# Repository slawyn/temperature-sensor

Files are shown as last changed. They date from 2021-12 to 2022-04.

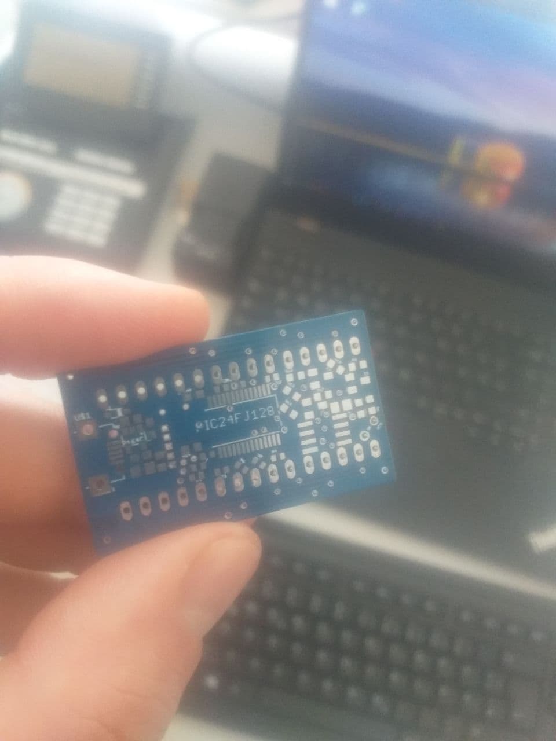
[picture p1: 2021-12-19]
pictures/photo_2021-05-17_21-20-24.jpg

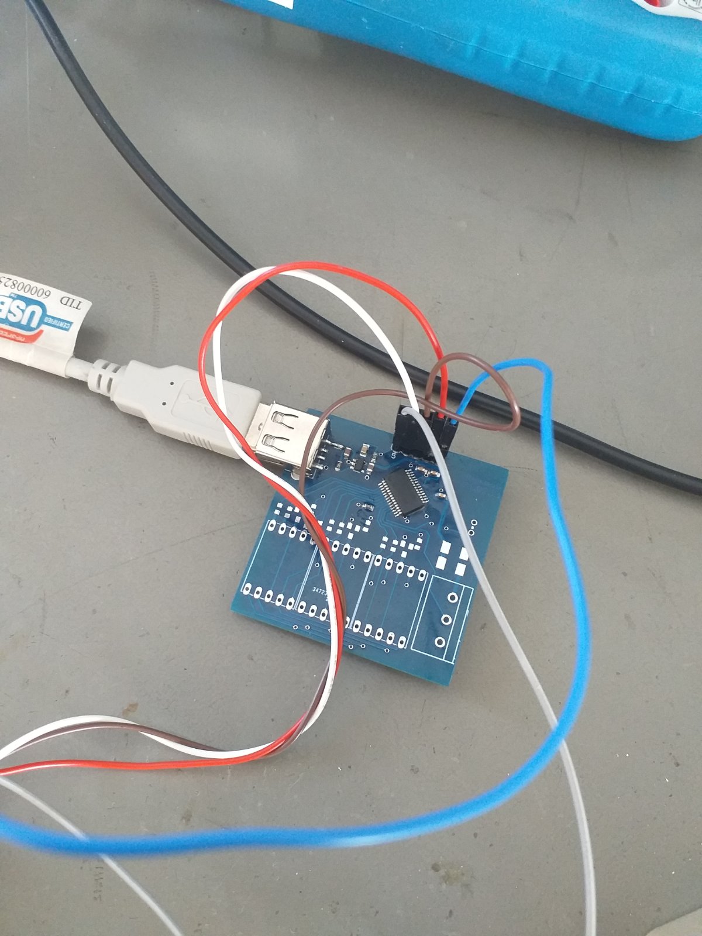
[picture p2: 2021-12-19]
pictures/viber_image_2021-04-01_18-56-37.jpg

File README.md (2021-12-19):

This project focuses on creating a simple usb-powered hardware that measures temperature.
*v1 - initial faulty design. CA CK have for 7-segment been switched
*v2 - improved doubled-sided design. Potentiometer replaced by an digital spi controller poti. Problem with the vias.
*v3 - wip

Use "Gerberlogix" to viewer gerber files.

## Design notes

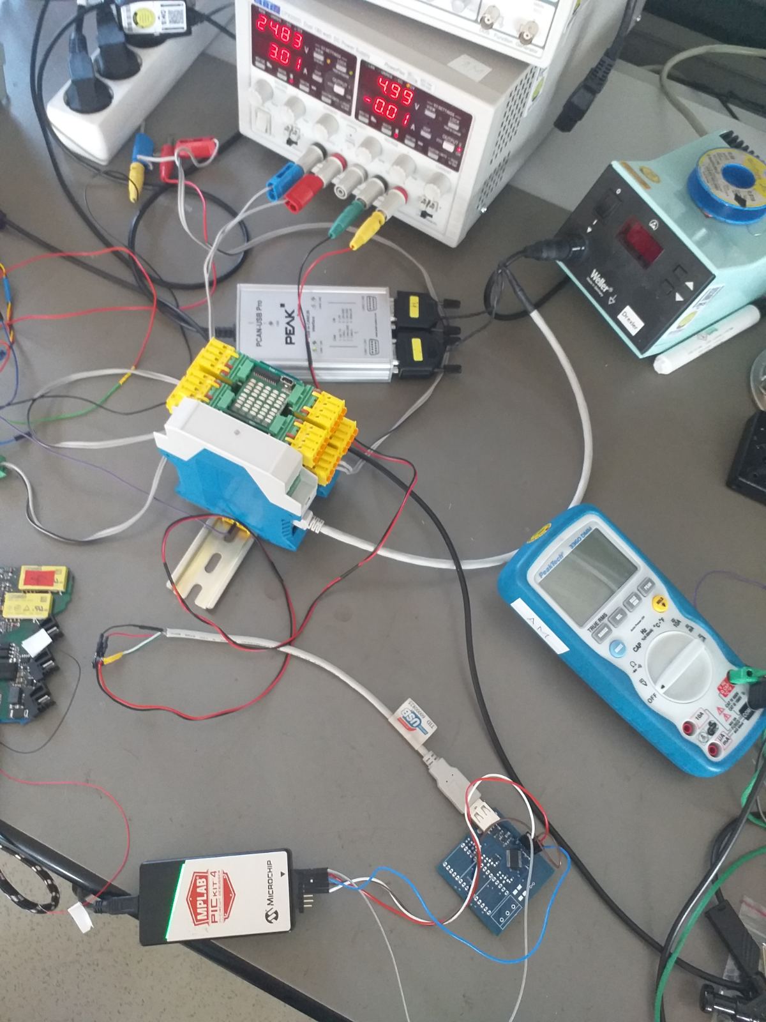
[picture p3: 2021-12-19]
pictures/viber_image_2021-04-01_18-56-36.jpg

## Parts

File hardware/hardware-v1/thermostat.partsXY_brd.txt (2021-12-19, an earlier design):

Parts List with XY on brd
i	Name	Package	Value	(X Y) [mil]	Angle	Layer	Height
[00]	C1	C0603	1u	( 461.024 1617.717)	  270.00	 1	*
[01]	C2	C0805	100n	( 598.425 1700.787)	   90.00	 1	*
[02]	C7	C0603	1u	( 709.055 1543.307)	  270.00	 1	*
[03]	CADDBUF	C0603	100n	(1401.181 1501.181)	    0.00	 1	*
[04]	CBUF	C0603	100n	(1275.197 1686.220)	    0.00	 1	*
[05]	C_CAP	C0603	100n	(1155.118 1686.220)	    0.00	 1	*
[06]	D2	SOD323_ST	BAT60J	( 354.331 1661.417)	  180.00	 1	*
[07]	DIS1	HDSP-M	HD-H101	( 236.220  444.882)	    0.00	 1	*
[08]	DIS2	HDSP-M	HD-H101	( 740.157  448.819)	    0.00	 1	*
[09]	DIS3	HDSP-M	HD-H101	(1240.157  448.819)	    0.00	 1	*
[10]	NCP164C	TSOP-5	-	( 594.882 1540.945)	  270.00	 1	*
[11]	NTC	0204V	1k bei 25C	(1740.945 1307.480)	   90.00	 1	*
[12]	Q1	SOT23-BEC	BCF30SMD	( 236.220  914.961)	  180.00	 1	*
[13]	Q2	SOT23-BEC	BCF30SMD	( 737.402  922.835)	  180.00	 1	*
[14]	Q3	SOT23-BEC	BCF30SMD	(1238.583  918.898)	  180.00	 1	*
[15]	R1	R2010	1k	(1653.150  907.874)	    0.00	 1	*
[16]	R3	R0603	47	(  35.827  909.843)	  270.00	 1	*
[17]	R4	R0603	47	( 437.402  870.866)	  270.00	 1	*
[18]	R5	R0603	47	( 331.102  867.323)	  270.00	 1	*
[19]	R6	R0603	47	( 535.827  914.961)	  270.00	 1	*
[20]	R7	R0603	47	(1039.764  919.291)	  270.00	 1	*
[21]	R8	R0603	47	(1134.252  919.685)	  270.00	 1	*
[22]	R9	R0603	47	( 134.252  908.268)	  270.00	 1	*
[23]	R10	R0603	330	(1331.890 1005.512)	  270.00	 1	*
[24]	R11	R0603	47	( 630.315  917.323)	  270.00	 1	*
[25]	R12	R0603	330	( 847.638 1012.598)	  270.00	 1	*
[26]	R13	R0603	330	( 331.890 1000.000)	  270.00	 1	*
[27]	R14	R0603	100	( 800.000 1186.220)	    0.00	 1	*
[28]	R15	R0603	10k	( 421.654 1473.228)	  270.00	 1	*
[29]	R16	R2010	1k	(1652.362 1053.543)	    0.00	 1	*
[30]	R18	3RP/1610N	1k	(1742.913  451.969)	   90.00	 1	*
[31]	RCLR	R0603	10k	( 709.055 1664.567)	  270.00	 1	*
[32]	SV1	MA05-1	-	(1075.984 1827.559)	  180.00	 1	*
[33]	U$2	SSOP28	-	(1064.961 1420.079)	  315.00	 1	*
[34]	X2	USB-A-S	-	(  86.614 1543.307)	    0.00	 1	*

Number of parts:35

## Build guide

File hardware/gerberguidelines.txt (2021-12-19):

https://www.7pcb.com/blog/common-gerber-issues-how-to-fix-them.php

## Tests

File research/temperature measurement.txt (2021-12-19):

-> NTC Thermistor 
   https://eu.mouser.com/Circuit-Protection/Thermistors/NTC-Thermistors/_/N-axfvt?P=1yiw4toZ1z0wuod
   * 2003     Temperature Range -30 to 45 

-> PIC uC 
  type: SSOP-28 
  https://www.mouser.de/ProductDetail/Microchip-Technology/PIC24FJ128GL302-E-SS/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

-> Voltage regulator
  type: TSOP-5
  https://www.mouser.de/ProductDetail/ON-Semiconductor/NCP164CSN330T1G/?qs=xZ%2FP%252Ba9zWqbi%2FAyy5UtoRw%3D%3D

1- RP2
6 - RP26
7 - RP19
9 - RP18
10 - RP28
11 - RP1
12 - RP0
13 - RP6
14 - RP7
17 - RP15
18 - RP14
19 - RP29
20 - RP31
26 - RPI37

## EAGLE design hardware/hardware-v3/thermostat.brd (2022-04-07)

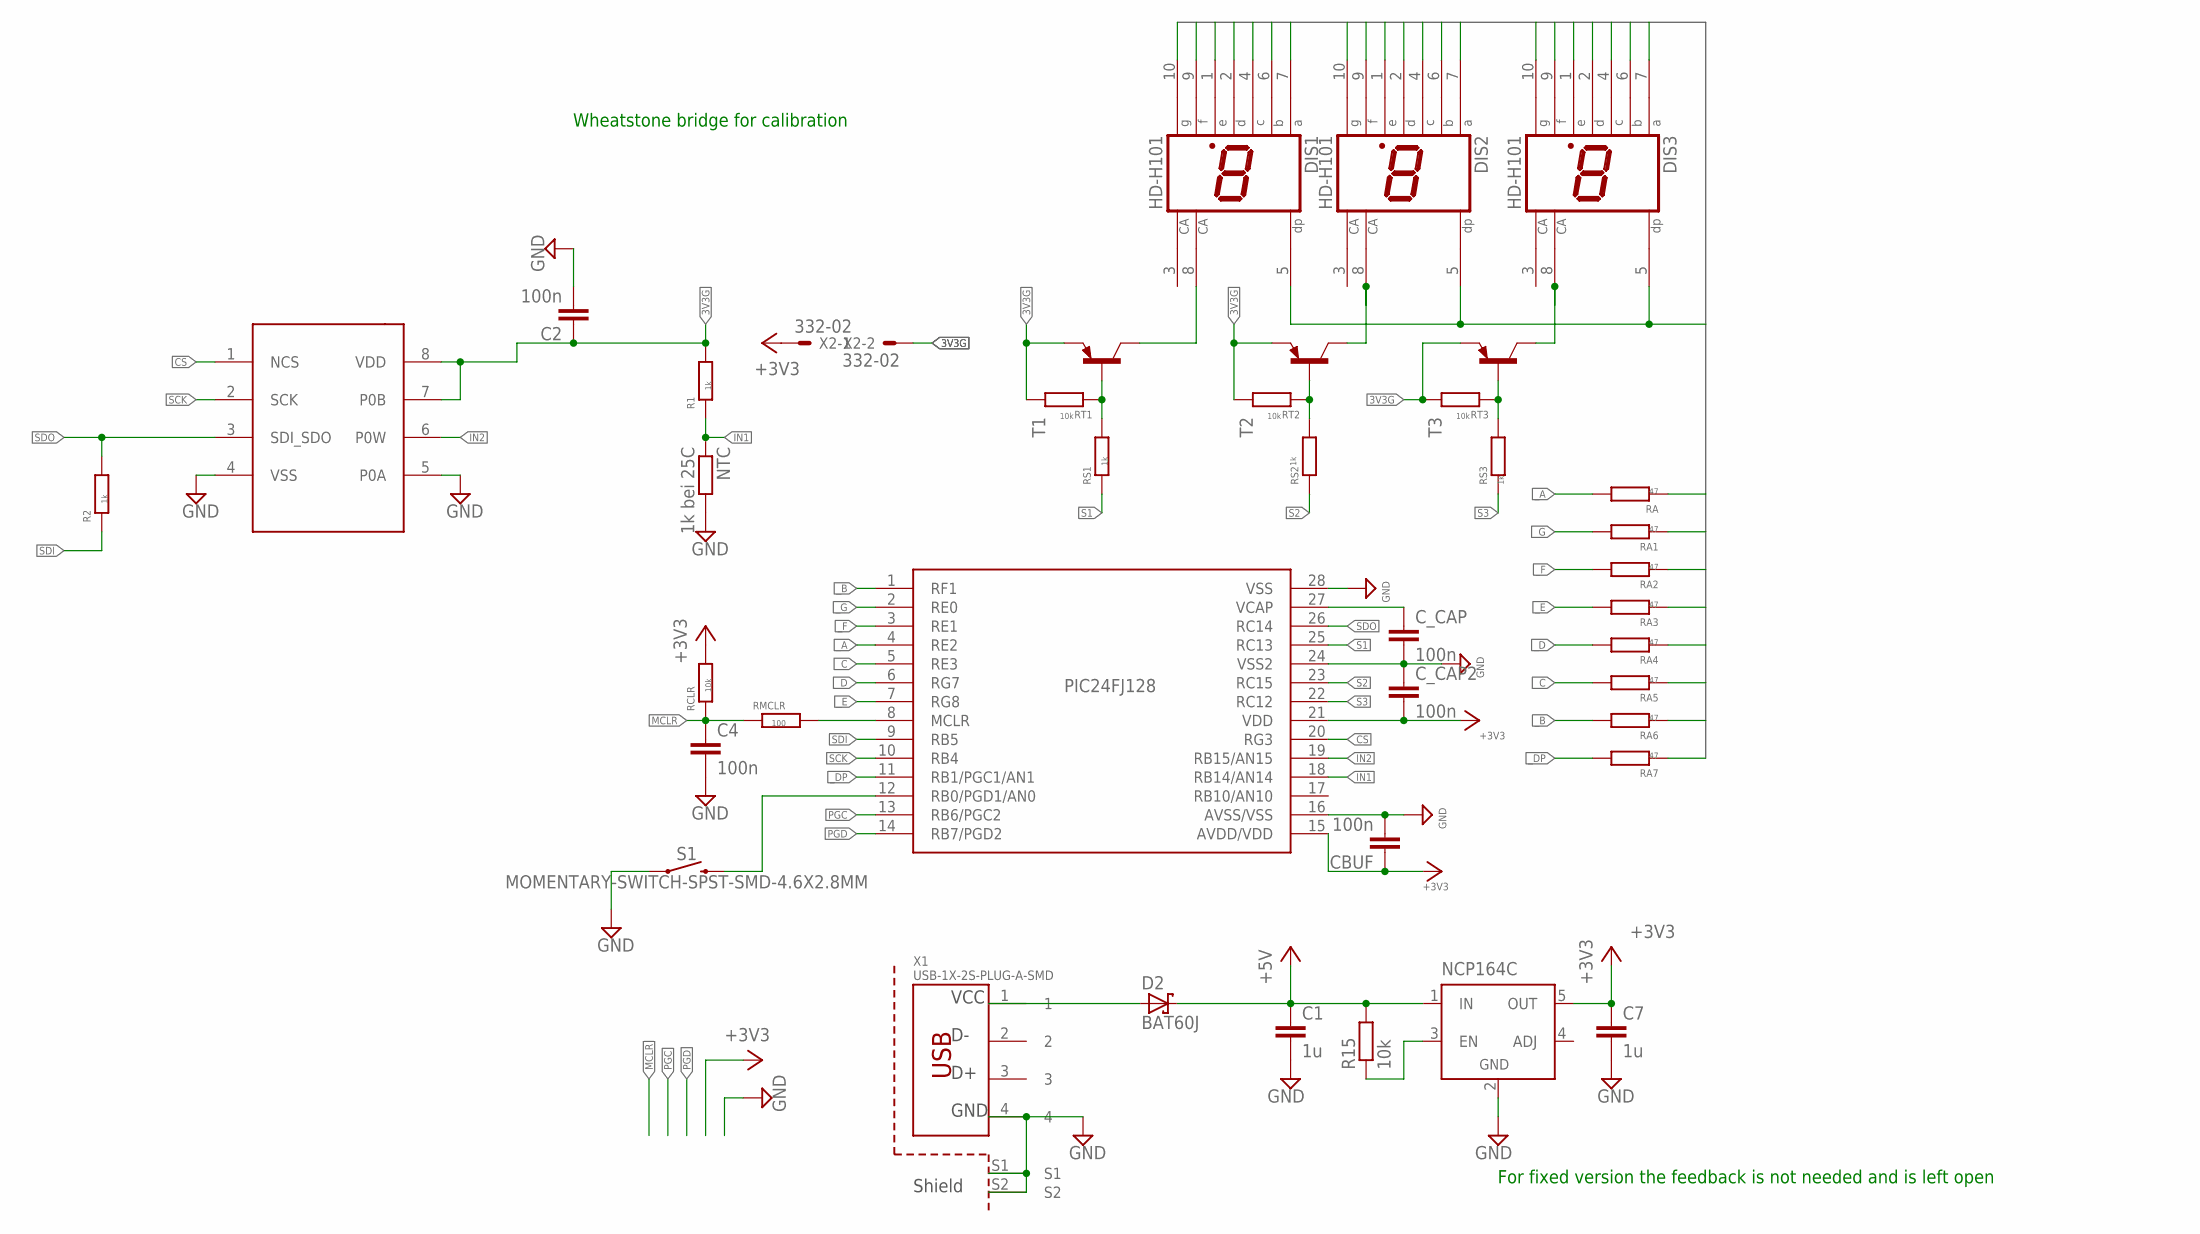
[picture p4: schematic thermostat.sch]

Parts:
C1, C7: 1u; C0603
C2, C4: 100n; C0603
CBUF: 100n; C0603
C_CAP, C_CAP2: 100n; C0603
D2: BAT60J; SOD323_ST
DIS1, DIS2, DIS3: HD-H101; HDSP-M
NCP164C: -; TSOP-5
NTC: 1k bei 25C; 0204V
R1, R2: 1k; R0603
R15: 10k; R0603
RA, RA1, RA2, RA3, RA4, RA5, RA6, RA7: 47; R0603
RCLR: 10k; R0603
RMCLR: 100; R0603
RS1, RS2, RS3: 1k; R0603
RT1, RT2, RT3: 10k; R0603
S1: MOMENTARY-SWITCH-SPST-SMD-4.6X2.8MM; TACTILE_SWITCH_SMD_4.6X2.8MM
T1, T2, T3: -PNP-SOT23-BCE; SOT23-BCE
U$1: MCP4151; SO-08
U$2: -; SSOP28
X1: USB-1X-2S-PLUG-A-SMD; USB-PLUG-A-SMD-2S
X2: 332-02

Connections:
3V3G: C2.1, R1.2, RT1.2, RT2.2, RT3.2, T1.E, T2.E, T3.E, U$1.7 (P0B), U$1.8 (VDD), X2.2
+3V3: C7.1, CBUF.1, C_CAP2.2, NCP164C.5 (OUT), RCLR.2, U$2.15 (AVDD/VDD), U$2.21 (VDD), X2.1
+5V: C1.1, D2.C, NCP164C.1 (IN), R15.2
A: DIS1.7 (A), DIS2.7 (A), DIS3.7 (A), RA.1
B: DIS1.6 (B), DIS2.6 (B), DIS3.6 (B), RA6.1
C: DIS1.4 (C), DIS2.4 (C), DIS3.4 (C), RA5.1
CS: U$1.1 (NCS), U$2.20 (RG3)
D: DIS1.2 (D), DIS2.2 (D), DIS3.2 (D), RA4.1
DP: DIS1.5 (DP), DIS2.5 (DP), DIS3.5 (DP), RA7.1
E: DIS1.1 (E), DIS2.1 (E), DIS3.1 (E), RA3.1
F: DIS1.9 (F), DIS2.9 (F), DIS3.9 (F), RA2.1
G: DIS1.10 (G), DIS2.10 (G), DIS3.10 (G), RA1.1
GND: C1.2, C2.2, C4.2, C7.2, CBUF.2, C_CAP.2, C_CAP2.1, NCP164C.2 (GND), NTC.2, S1.1, S1.2 (1), U$1.4 (VSS), U$1.5 (P0A), U$2.16 (AVSS/VSS), U$2.24 (VSS2), U$2.28 (VSS), X1.4, X1.S1, X1.S2
IN1: NTC.1, R1.1, U$2.18 (RB14/AN14)
IN2: U$1.6 (P0W), U$2.19 (RB15/AN15)
MCLR: C4.1, RCLR.1, RMCLR.1
unnamed: NCP164C.3 (EN), R15.1
unnamed: C_CAP.1, U$2.27 (VCAP)
unnamed: RS1.2, RT1.1, T1.B
unnamed: D2.A, X1.1
unnamed: RMCLR.2, U$2.8 (MCLR)
unnamed: RS3.2, RT3.1, T3.B
unnamed: RS2.2, RT2.1, T2.B
unnamed: DIS1.8 (CA), T1.C
unnamed: DIS2.8 (CA), T2.C
unnamed: DIS3.8 (CA), T3.C
unnamed: S1.3 (2), S1.4 (2), U$2.12 (RB0/PGD1/AN0)
PGC: U$2.13 (RB6/PGC2)
PGD: U$2.14 (RB7/PGD2)
S1: RS1.1, U$2.25 (RC13)
S2: RS2.1, U$2.23 (RC15)
S3: RS3.1, U$2.22 (RC12)
SCK: U$1.2 (SCK), U$2.10 (RB4)
SDI: R2.1, U$2.9 (RB5)
SDO: R2.2, U$1.3 (SDI_SDO), U$2.26 (RC14)
_A: RA.2, U$2.4 (RE2)
_B: RA6.2, U$2.1 (RF1)
_C: RA5.2, U$2.5 (RE3)
_D: RA4.2, U$2.6 (RG7)
_DP: RA7.2, U$2.11 (RB1/PGC1/AN1)
_E: RA3.2, U$2.7 (RG8)
_F: RA2.2, U$2.3 (RE1)
_G: RA1.2, U$2.2 (RE0)

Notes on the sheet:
For fixed version the feedback is not needed and is left open
Wheatstone bridge for calibration

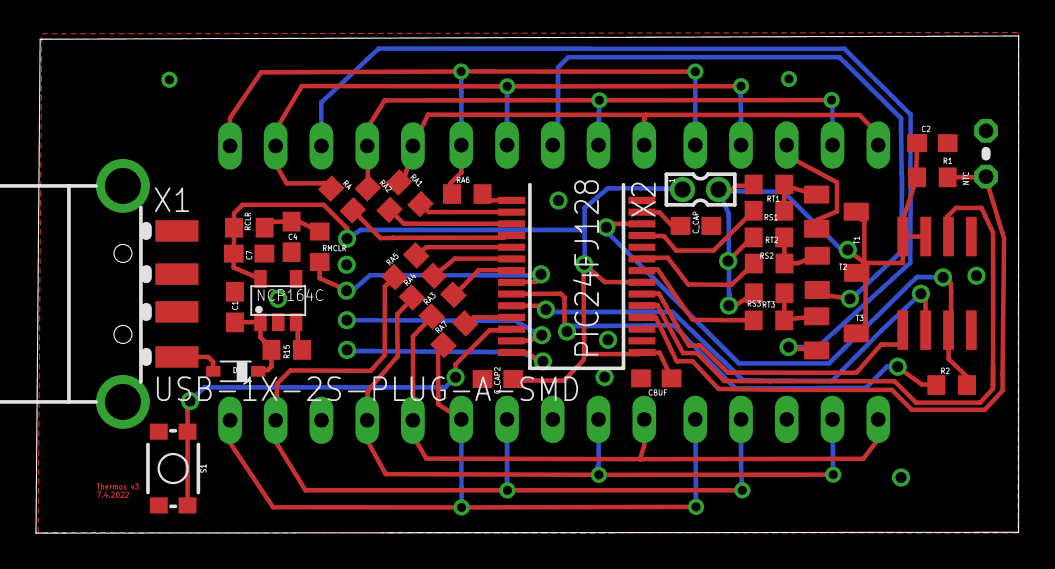
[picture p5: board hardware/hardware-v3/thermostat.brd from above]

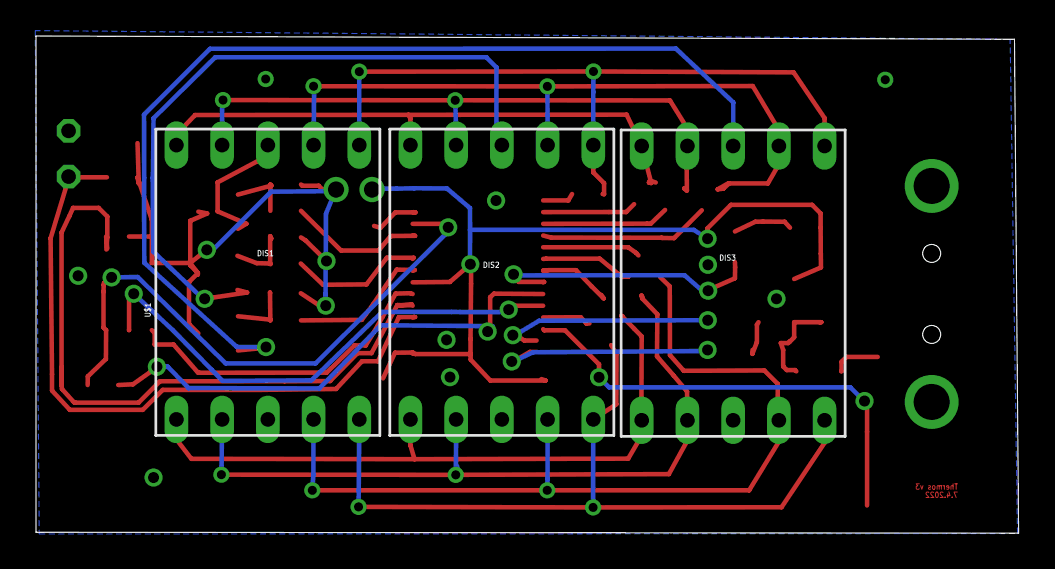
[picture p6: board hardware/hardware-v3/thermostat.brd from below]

Board: 2 copper layers, 54.6 x 27.6 mm, 40 parts (3 on the bottom side), 41 nets.

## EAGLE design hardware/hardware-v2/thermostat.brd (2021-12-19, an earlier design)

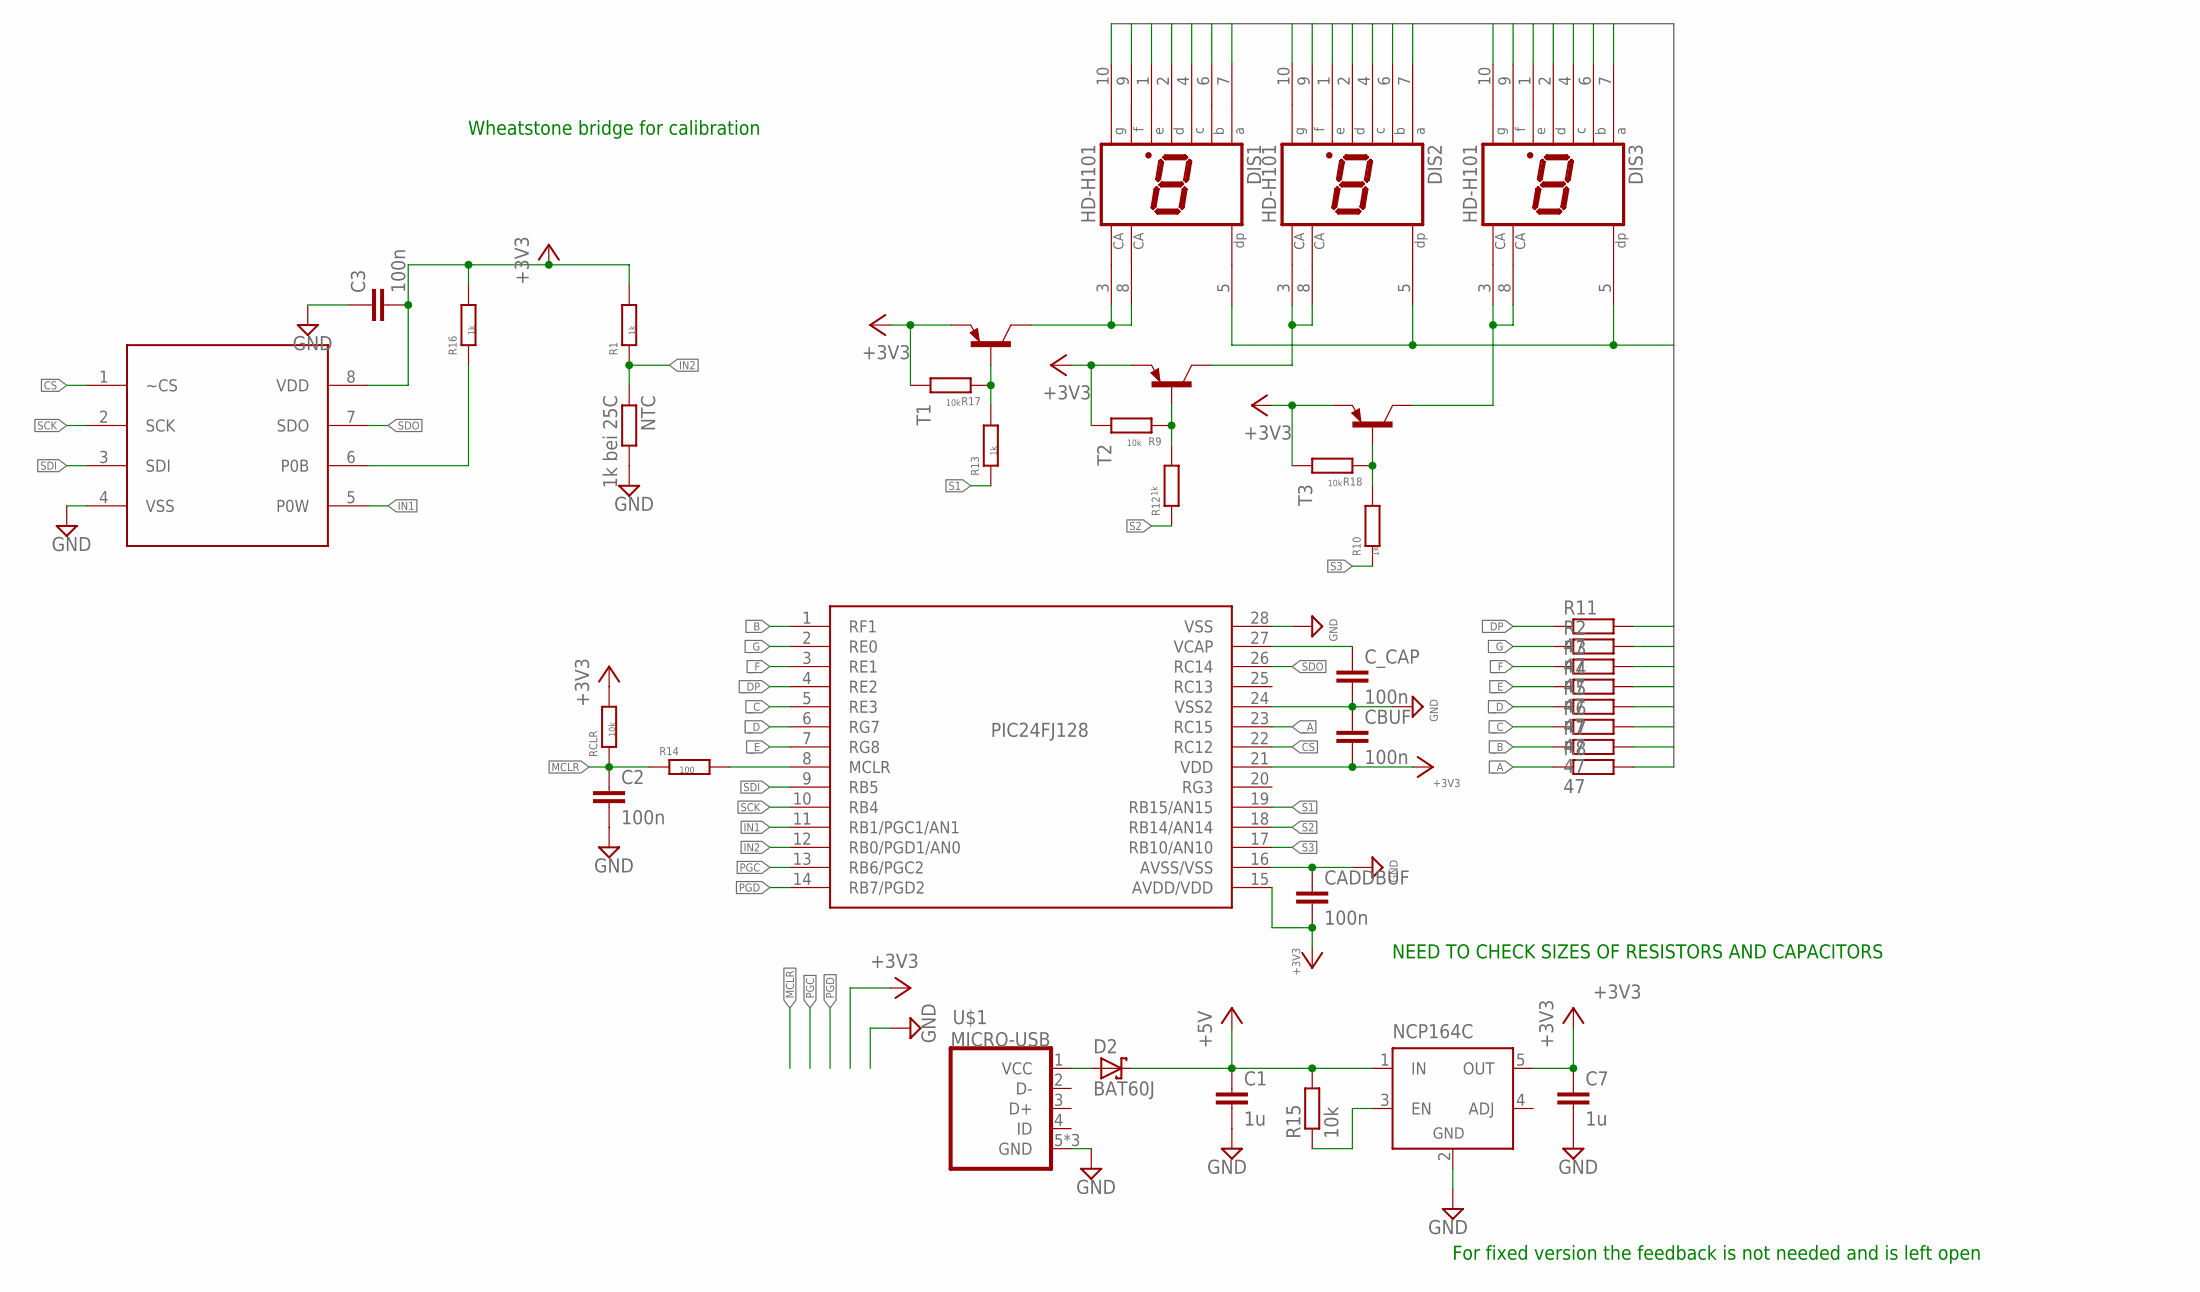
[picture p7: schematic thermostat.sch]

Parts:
C1, C7: 1u; C0603
C2, C3: 100n; C0805
CADDBUF: 100n; C0402
CBUF: 100n; C0402
C_CAP: 100n; C0603
D2: BAT60J; SOD323_ST
DIS1, DIS2, DIS3: HD-H101; HDSP-M
NCP164C: -; TSOP-5
NTC: 1k bei 25C; 0204V
R1, R10, R12, R13, R16: 1k; R0603
R2, R3, R4, R5, R6, R7, R8, R11: 47; R0402
R9, R15, R17, R18: 10k; R0603
R14: 100; R0603
RCLR: 10k; R0603
T1, T2, T3: -PNP-SOT23-BCE; SOT23-BCE
U$1: MICRO-USB
U$2: -; SSOP28
U$3: MCP4141-103; SO-08

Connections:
+3V3: C3.2, C7.1, CADDBUF.2, CBUF.2, NCP164C.5 (OUT), R1.2, R9.2, R16.2, R17.2, R18.2, RCLR.2, T1.E, T2.E, T3.E, U$2.15 (AVDD/VDD), U$2.21 (VDD), U$3.8 (VDD)
+5V: C1.1, D2.C, NCP164C.1 (IN), R15.2
A: DIS1.7 (A), DIS2.7 (A), DIS3.7 (A), R8.2
B: DIS1.6 (B), DIS2.6 (B), DIS3.6 (B), R7.2
C: DIS1.4 (C), DIS2.4 (C), DIS3.4 (C), R6.2
CS: U$2.22 (RC12), U$3.1 (~CS)
D: DIS1.2 (D), DIS2.2 (D), DIS3.2 (D), R5.2
DP: DIS1.5 (DP), DIS2.5 (DP), DIS3.5 (DP), R11.2
E: DIS1.1 (E), DIS2.1 (E), DIS3.1 (E), R4.2
F: DIS1.9 (F), DIS2.9 (F), DIS3.9 (F), R3.2
G: DIS1.10 (G), DIS2.10 (G), DIS3.10 (G), R2.2
GND: C1.2, C2.2, C3.1, C7.2, CADDBUF.1, CBUF.1, C_CAP.2, NCP164C.2 (GND), NTC.2, U$1.5 (GND), U$1.GND1 (GND), U$1.GND2 (GND), U$2.16 (AVSS/VSS), U$2.24 (VSS2), U$2.28 (VSS), U$3.4 (VSS)
IN1: U$2.11 (RB1/PGC1/AN1), U$3.5 (P0W)
IN2: NTC.1, R1.1, U$2.12 (RB0/PGD1/AN0)
MCLR: C2.1, R14.1, RCLR.1
unnamed: NCP164C.3 (EN), R15.1
unnamed: R16.1, U$3.6 (P0B)
unnamed: C_CAP.1, U$2.27 (VCAP)
unnamed: R13.2, R17.1, T1.B
unnamed: D2.A, U$1.1 (VCC)
unnamed: R14.2, U$2.8 (MCLR)
unnamed: R10.2, R18.1, T3.B
unnamed: R9.1, R12.2, T2.B
unnamed: DIS1.3 (CA), DIS1.8 (CA), T1.C
unnamed: DIS2.3 (CA), DIS2.8 (CA), T2.C
unnamed: DIS3.3 (CA), DIS3.8 (CA), T3.C
PGC: U$2.13 (RB6/PGC2)
PGD: U$2.14 (RB7/PGD2)
S1: R13.1, U$2.19 (RB15/AN15)
S2: R12.1, U$2.18 (RB14/AN14)
S3: R10.1, U$2.17 (RB10/AN10)
SCK: U$2.10 (RB4), U$3.2 (SCK)
SDI: U$2.9 (RB5), U$3.3 (SDI)
SDO: U$2.26 (RC14), U$3.7 (SDO)
_A: R8.1, U$2.23 (RC15)
_B: R7.1, U$2.1 (RF1)
_C: R6.1, U$2.5 (RE3)
_D: R5.1, U$2.6 (RG7)
_DP: R11.1, U$2.4 (RE2)
_E: R4.1, U$2.7 (RG8)
_F: R3.1, U$2.3 (RE1)
_G: R2.1, U$2.2 (RE0)

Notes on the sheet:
NEED TO CHECK SIZES OF RESISTORS AND CAPACITORS
For fixed version the feedback is not needed and is left open
Wheatstone bridge for calibration

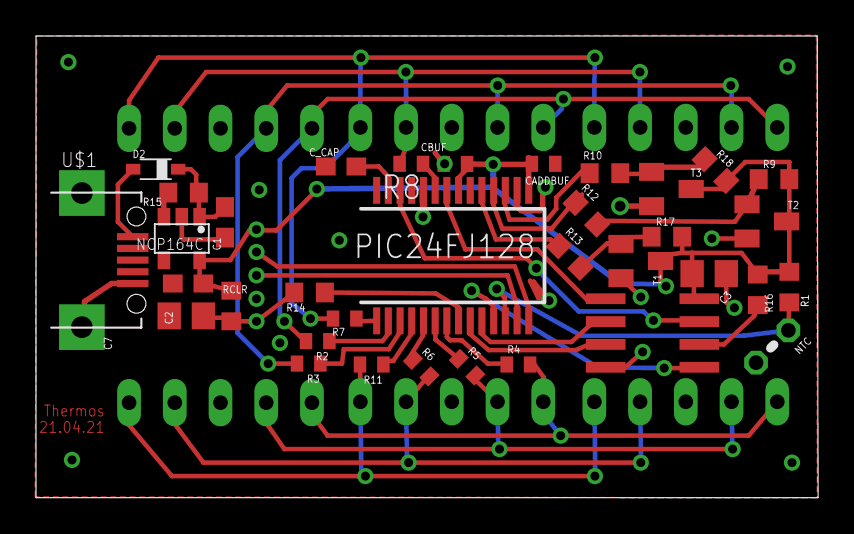
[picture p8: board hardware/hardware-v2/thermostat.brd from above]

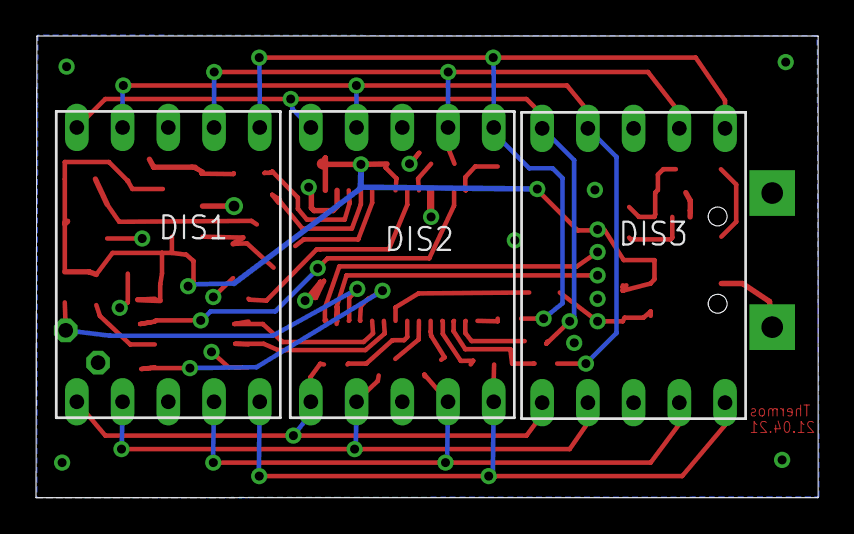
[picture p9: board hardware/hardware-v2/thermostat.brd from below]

Board: 4 copper layers, 43.5 x 25.6 mm, 38 parts (3 on the bottom side), 40 nets.

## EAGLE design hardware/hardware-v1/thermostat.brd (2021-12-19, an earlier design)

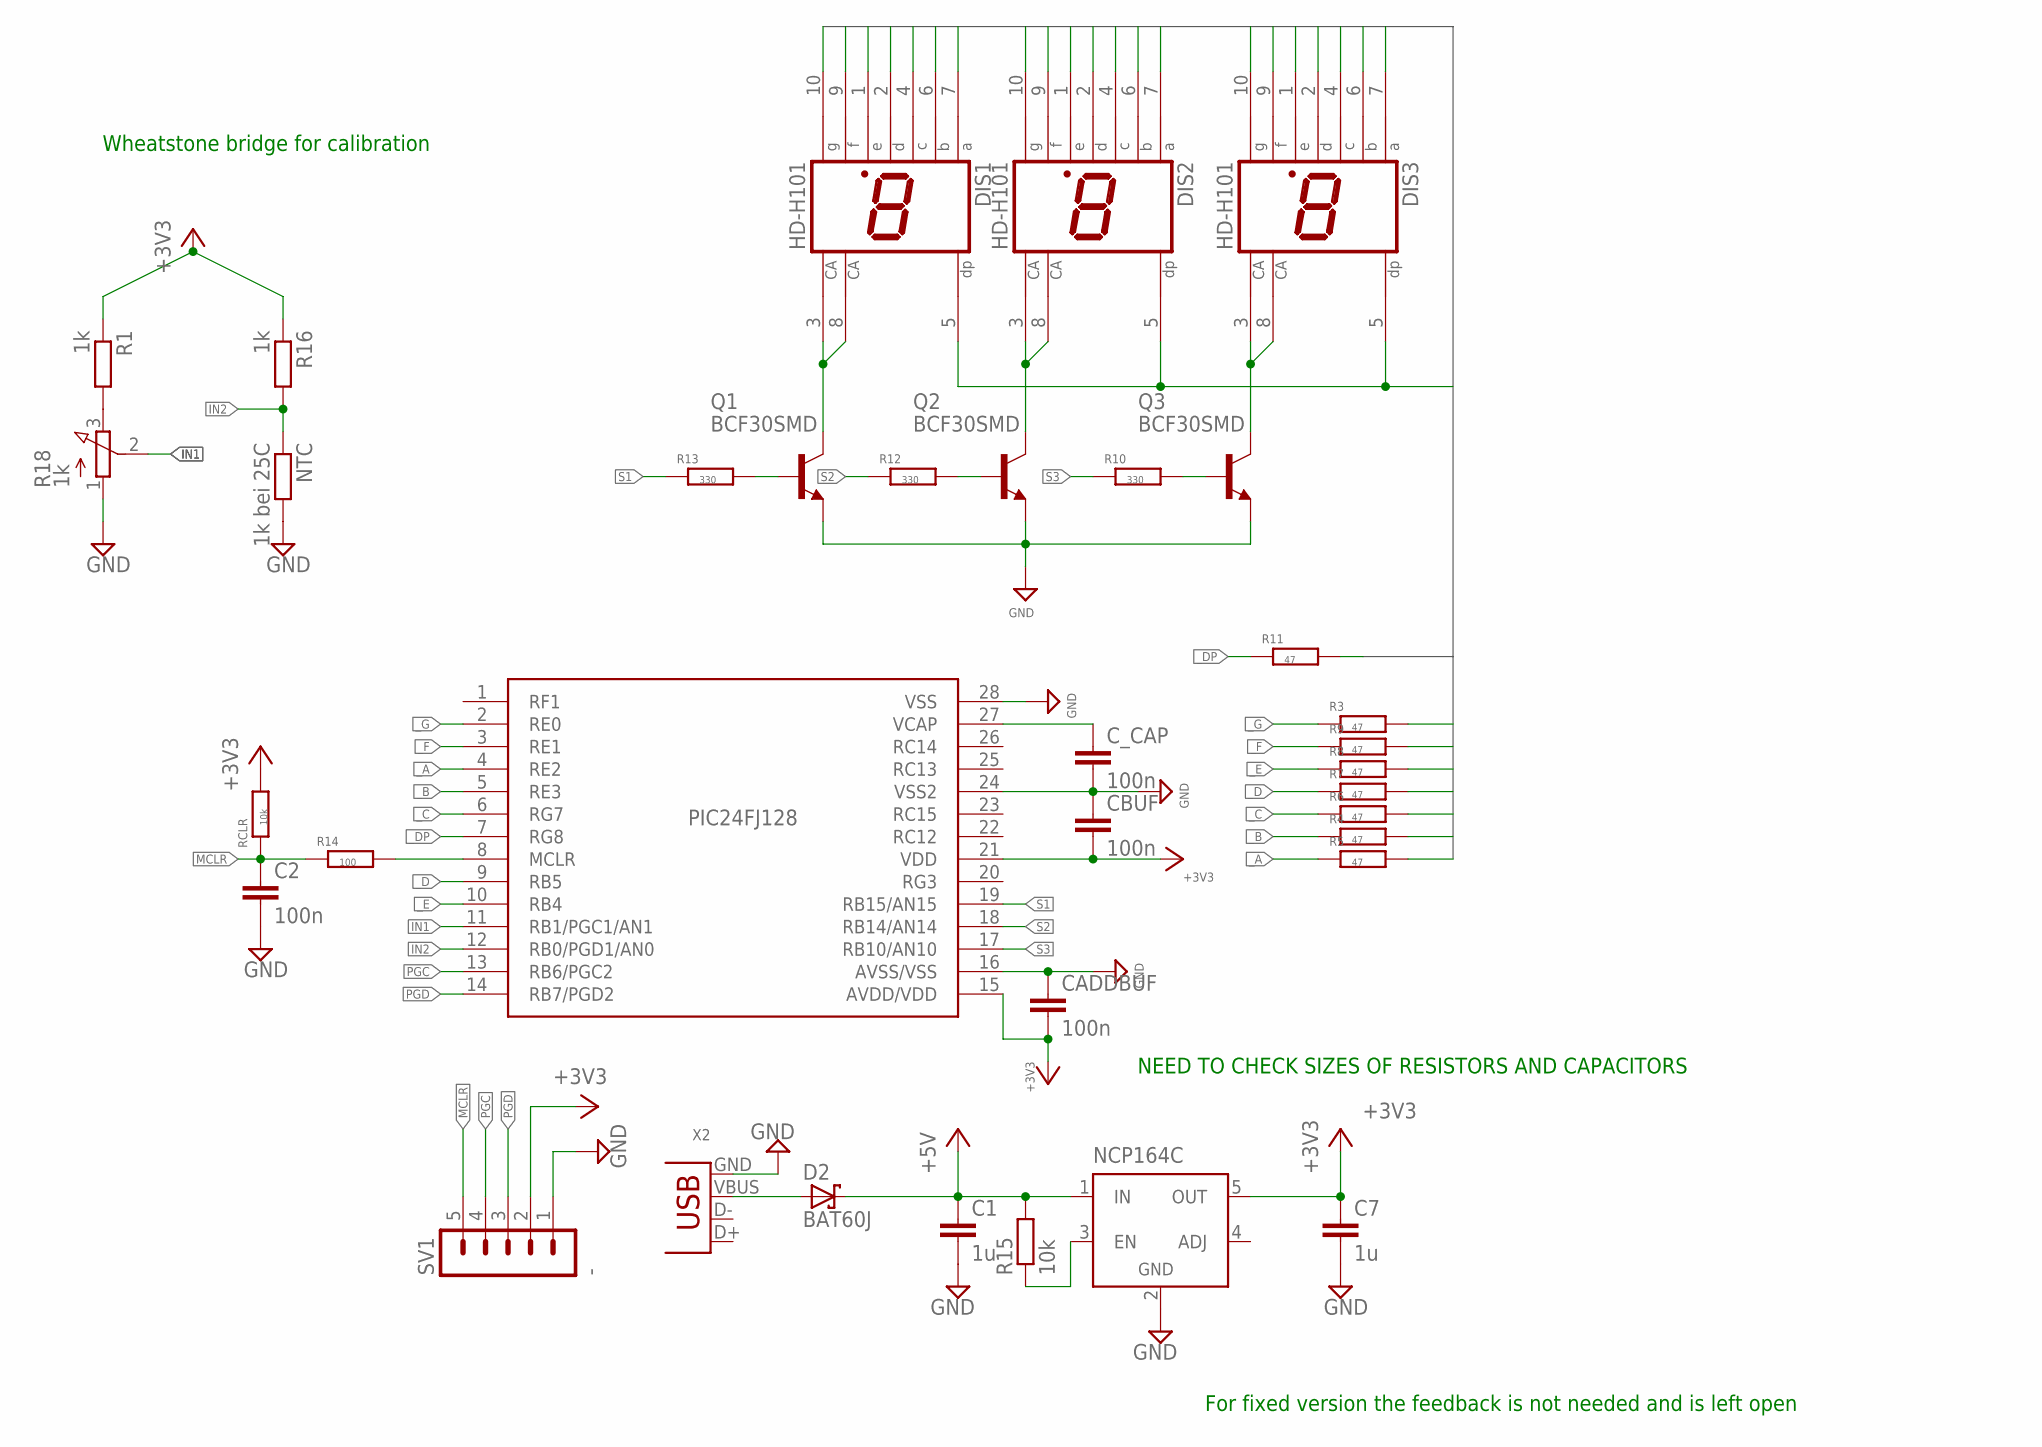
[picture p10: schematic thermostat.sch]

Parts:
C1, C7: 1u; C0603
C2: 100n; C0805
CADDBUF: 100n; C0603
CBUF: 100n; C0603
C_CAP: 100n; C0603
D2: BAT60J; SOD323_ST
DIS1, DIS2, DIS3: HD-H101; HDSP-M
NCP164C: -; TSOP-5
NTC: 1k bei 25C; 0204V
Q1, Q2, Q3: BCF30SMD; SOT23-BEC
R1, R16: 1k; R2010
R3, R4, R5, R6, R7, R8, R9, R11: 47; R0603
R10, R12, R13: 330; R0603
R14: 100; R0603
R15: 10k; R0603
R18: 1k; 3RP/1610N
RCLR: 10k; R0603
SV1: -; MA05-1
U$2: -; SSOP28
X2: -; USB-A-S

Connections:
+3V3: C7.1, CADDBUF.2, CBUF.2, NCP164C.5 (OUT), R1.1, R16.1, RCLR.2, SV1.2, U$2.15 (AVDD/VDD), U$2.21 (VDD)
+5V: C1.1, D2.C, NCP164C.1 (IN), R15.2
A: DIS1.7 (A), DIS2.7 (A), DIS3.7 (A), R5.2
B: DIS1.6 (B), DIS2.6 (B), DIS3.6 (B), R4.2
C: DIS1.4 (C), DIS2.4 (C), DIS3.4 (C), R6.2
D: DIS1.2 (D), DIS2.2 (D), DIS3.2 (D), R7.2
DP: DIS1.5 (DP), DIS2.5 (DP), DIS3.5 (DP), R11.2
E: DIS1.1 (E), DIS2.1 (E), DIS3.1 (E), R8.2
F: DIS1.9 (F), DIS2.9 (F), DIS3.9 (F), R9.2
G: DIS1.10 (G), DIS2.10 (G), DIS3.10 (G), R3.2
GND: C1.2, C2.2, C7.2, CADDBUF.1, CBUF.1, C_CAP.2, NCP164C.2 (GND), NTC.2, Q1.E, Q2.E, Q3.E, R18.1 (A), SV1.1, U$2.16 (AVSS/VSS), U$2.24 (VSS2), U$2.28 (VSS), X2.GND
IN1: R18.2 (S), U$2.11 (RB1/PGC1/AN1)
IN2: NTC.1, R16.2, U$2.12 (RB0/PGD1/AN0)
MCLR: C2.1, R14.1, RCLR.1, SV1.5
unnamed: NCP164C.3 (EN), R15.1
unnamed: R1.2, R18.3 (E)
unnamed: C_CAP.1, U$2.27 (VCAP)
unnamed: D2.A, X2.VBUS
unnamed: R14.2, U$2.8 (MCLR)
unnamed: DIS1.3 (CA), DIS1.8 (CA), Q1.C
unnamed: DIS2.3 (CA), DIS2.8 (CA), Q2.C
unnamed: DIS3.3 (CA), DIS3.8 (CA), Q3.C
unnamed: Q1.B, R13.2
unnamed: Q2.B, R12.2
unnamed: Q3.B, R10.2
PGC: SV1.4, U$2.13 (RB6/PGC2)
PGD: SV1.3, U$2.14 (RB7/PGD2)
S1: R13.1, U$2.19 (RB15/AN15)
S2: R12.1, U$2.18 (RB14/AN14)
S3: R10.1, U$2.17 (RB10/AN10)
_A: R5.1, U$2.4 (RE2)
_B: R4.1, U$2.5 (RE3)
_C: R6.1, U$2.6 (RG7)
_D: R7.1, U$2.9 (RB5)
_DP: R11.1, U$2.7 (RG8)
_E: R8.1, U$2.10 (RB4)
_F: R9.1, U$2.3 (RE1)
_G: R3.1, U$2.2 (RE0)

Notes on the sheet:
NEED TO CHECK SIZES OF RESISTORS AND CAPACITORS
For fixed version the feedback is not needed and is left open
Wheatstone bridge for calibration

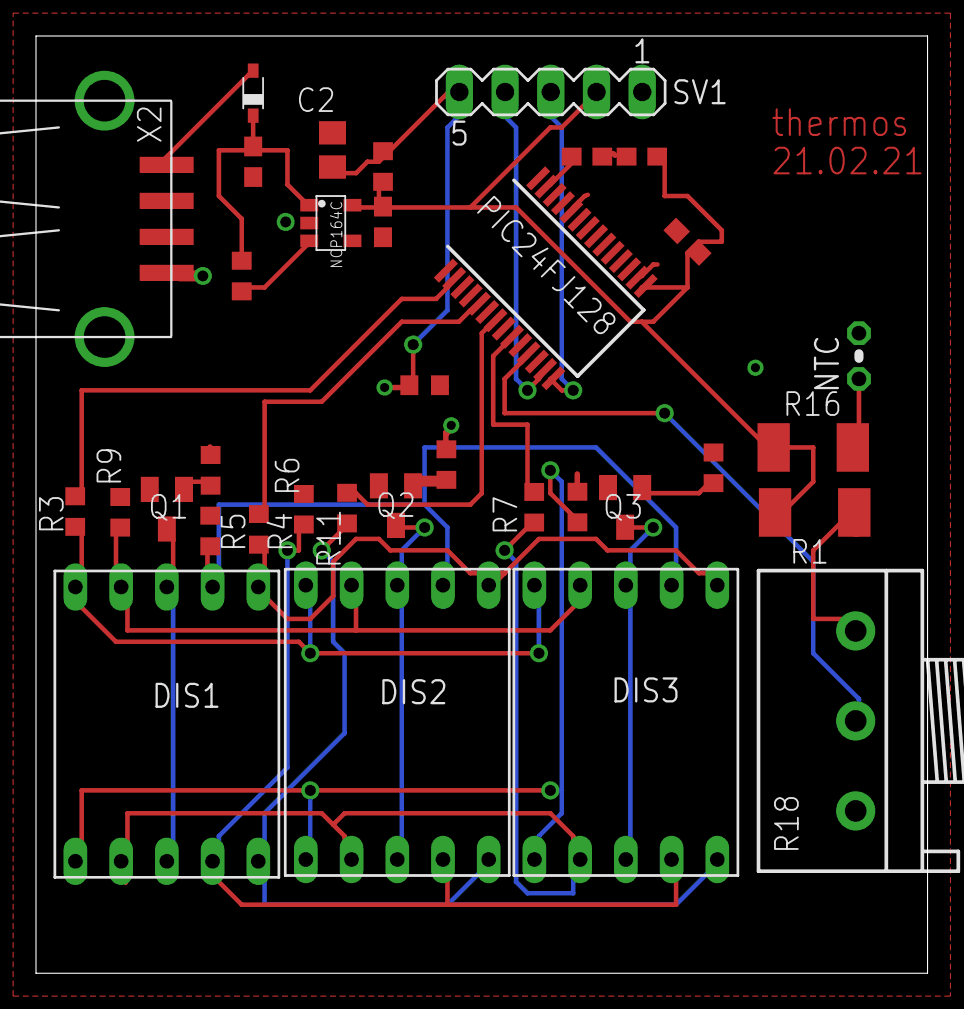
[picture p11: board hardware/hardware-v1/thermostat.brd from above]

Board: 2 copper layers, 49.5 x 52.1 mm, 35 parts (0 on the bottom side), 38 nets.

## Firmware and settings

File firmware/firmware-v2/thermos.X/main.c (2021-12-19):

/*
 * File:   newmainXC16.c
 * Author: slaw
 *
 * Created on April 10, 2021, 12:51 AM
 */

#include "typedefs.h"
#include "configbits.h"
#include "prototypes.h"
#include "controls.h"

/*******************************
 *      Global Variables
 *******************************/
extern const int16_t arri16QTemperatureValues[];
char arrchString[] = defString;
Status_t xScheduleStatus;
Adc_t xAdcStatus;
uint8_t ui8TrapErrorStatus;

/*****************************
 * 
 * Send Data to Poti using SPI 16-bit
 * 
 *****************************/
uint16_t ui16SpiCommunicatePoti(uint8_t ui8Command, uint8_t ui8Data){
    uint16_t ui16ReceivedData;

    SPI1CON1Lbits.SPIEN= 0;
    SPI1CON1Lbits.MODE = 1;        
    SPI1CON1Lbits.SPIEN= 1;        // Enable 16-bit Mode
    
    defSpiCsPoti(0);
    vWaitCycles(defSpiCsWaitCycles);
    
    SPI1BUFL = ((uint16_t)ui8Command)<<8|ui8Data;
    while(SPI1STATLbits.SPIBUSY);
    ui16ReceivedData = SPI1BUFL;
    defSpiCsPoti(1);
    
    return ui16ReceivedData;
}
/*****************************
 * 
 * Send Data to Poti using SPI 16-bit
 * 
 *****************************/
uint8_t ui8SpiCommunicatePoti(uint8_t ui8Command){
    uint16_t ui16ReceivedData;
    
    SPI1CON1Lbits.SPIEN= 0;
    SPI1CON1Lbits.MODE = 0;        
    SPI1CON1Lbits.SPIEN= 1;        // Enable 8-bit Mode
    
    defSpiCsPoti(0);
    vWaitCycles(defSpiCsWaitCycles);
    
    SPI1BUFL = ui8Command;
    while(SPI1STATLbits.SPIBUSY);
    ui16ReceivedData = SPI1BUFL;
    defSpiCsPoti(1);
    
    return (uint8_t)(ui16ReceivedData);
}

/*****************************
 * 
 * Show Character on Segment
 * 
 *****************************/
void vSetSegmentCharacter(uint8_t ui8SegmentCharacter, uint8_t ui8SelectSegment){
    defDisableSegments();
    defResetSegmentBars();
    
    if(ui8SegmentCharacter&0x80){
        defSetBarDP();
    }
    
    switch(ui8SegmentCharacter&0x7F){
        case '0':
            defSetBarA();
            defSetBarB();
            defSetBarC();
            defSetBarD();
            defSetBarE();
            defSetBarF();
            break;
        case '1':
            defSetBarB();
            defSetBarC();
            break;
        case 'Z':
        case '2':
            defSetBarA();
            defSetBarB();
            defSetBarG();
            defSetBarE();
            defSetBarD();
            break;
        case '3':
            defSetBarA();
            defSetBarB();
            defSetBarC();
            defSetBarD();
            defSetBarG()
            break;
        case '4':
            defSetBarB();
            defSetBarC();
            defSetBarF();
            defSetBarG()
            break;
        case 'S':
        case '5':
            defSetBarA();
            defSetBarC();
            defSetBarD();
            defSetBarF();
            defSetBarG()
            break;
        case '6':
            defSetBarA();
            defSetBarC();
            defSetBarD();
            defSetBarF();
            defSetBarE();
            defSetBarG();
            break;
        case '7':
            defSetBarA();
            defSetBarB();
            defSetBarC();
            break;
        case '8':
            defSetBarA();
            defSetBarB();
            defSetBarC();
            defSetBarD();
            defSetBarF();
            defSetBarE();
            defSetBarG();
            break;
        case '9':
            defSetBarA();
            defSetBarB();
            defSetBarC();
            defSetBarD();
            defSetBarF();
            defSetBarG();
            break;
        case 'A':
            defSetBarA();
            defSetBarB();
            defSetBarC();
            defSetBarF();
            defSetBarE();
            defSetBarG();
            break;
        case 'c':
            defSetBarD();
            defSetBarE();
            defSetBarG();
            break;
        case 'C':
            defSetBarA();
            defSetBarD();
            defSetBarF();
            defSetBarE();
            break;
        case 'E':
            defSetBarA();
            defSetBarD();
            defSetBarF();
            defSetBarE();
            defSetBarG();
            break;
        case 'F':
            defSetBarA();
            defSetBarF();
            defSetBarE();
            defSetBarG();
            break;
        case 'G':
            defSetBarA();
            defSetBarC();
            defSetBarD();
            defSetBarF();
            defSetBarE();
            break;
        case 'H':
            defSetBarB();
            defSetBarC();
            defSetBarF();
            defSetBarE();
            defSetBarG();
            break;
        case 'n':
            defSetBarA();
            defSetBarB();
            defSetBarC();
            defSetBarF();
            defSetBarE();
            break;
        case 'b':
            defSetBarC();
            defSetBarD();
            defSetBarF();
            defSetBarE();
            defSetBarG();
            break;
        case 'd':
            defSetBarB();
            defSetBarC();
            defSetBarD();
            defSetBarE();
            defSetBarG();
            break;
        case 'p':
            defSetBarA();
            defSetBarB();
            defSetBarF();
            defSetBarE();
            defSetBarG();
            break;
        case 'h':
            defSetBarC();
            defSetBarF();
            defSetBarE();
            defSetBarG();
            break;
        case 'j':
            defSetBarB();
            defSetBarC();
            defSetBarD();
            break;
        case 'L':
            defSetBarD();
            defSetBarF();
            defSetBarE();
            break;
        case '-':
            defSetBarG();
            break;
        case '_':
            defSetBarD();
            break;
        case ' ':
            break;
        default:
            break;
    }
    
    defEnableSegment(ui8SelectSegment);
}
/*****************************
 * 
 * Initialize Hardware
 * 
 *****************************/
void vInitHardware(){
   // Gpio Configuration
   //--------------------------------
    TRISG = 0x0000;   // RG7 In     D
                      // RG8 In     E
    TRISB = 0x0003;   // RB15 In
                      // RB14 In
                      // RB10 In 
                      // RB5 In  SDI 
                      // RB4 Out SCK
                      // RB0 In Analog IN2
                      // RB1 In Analog IN1
    TRISE = 0x0000;   // RE0 In G
                      // RE1 In F
                      // RE2 In DP
                      // RE3 In C
    TRISC = 0xC000;   // RC15 In A
                      // RC14 Out SDO
                      // RC13 Free
                      // RC12 Out CS
    TRISF = 0x0000;   // RF1  In  B
    ANSE = 0x0000;     
    ANSB = 0x0003;    // RB0 and RB1 analog inputs
    ANSG = 0x0000;

    //- Pin remapping
    RPOR9bits.RP18R =  7;           // SDI (SDO1. uc -> Poti)
    RPOR14bits.RP28R = 8;           // SCK (SCK1. uc -> Poti)
    RPINR20bits.SDI1R = 37;         // SDO(SDI1. uc <- Poti)
            
    // Clear Configurations
    //---------------------------------
    defDisableSegments();           // Bars
    defResetSegmentBars();          // Segments
    defSpiCsPoti(1);                // Cs
    
    RCON = 0x0000;                              // Clear "Reset cause"
    ui8TrapErrorStatus = 0;                     // Clear "Trap Error cause"
    xAdcStatus.ui16AdcNewDataAvailable = 0;     // Clear Adc Data Flag
    xScheduleStatus.ui16TimerSchedule = 0x0000; // Clear Timer Flags
    
    // Spi
    //--------------------------------
    SPI1CON1Lbits.SPIEN = 0;        // Disable Spi
    SPI1CON1Lbits.ENHBUF = 0;       // Standard Buffer
    SPI1CON1Lbits.DISSDO = 0;       // Sdo controlled by module
    SPI1CON1Lbits.DISSDI = 0;       // Sdi controlled by module
    SPI1CON1Lbits.DISSCK = 0;       // Sck controlled by module
    SPI1CON1Lbits.CKE = 1;          // Sample at rising edge
    SPI1CON1Lbits.CKP = 0;          // Idle High(MODE 0,0)
    SPI1CON1Lbits.MODE = 1;         // 16-bit Mode
    SPI1CON1Hbits.AUDEN = 0;        // cont. 8-bit Mode
    SPI1STATLbits.SPIROV = 0;       // Clear Offerflow
    
    SPI1BRGL = 0x000A;              // Set  Baud: Fpb/(2*(SPI1BRG+1))
 
    SPI1CON1Lbits.MSTEN = 1;        // Master Mode
    SPI1CON1Lbits.SPIEN = 1;

    // Adc: Smallest Clock: 300ns = 3.3Mhz
    // if FOSC is default FRC(8Mhz)/2 = 4 Mhz. ADC-Clock =  2/FOSC = 2Mhz. 
    // ((12*1/2000000 + 16*1/2000000)*16) -> Total Time 2.2 us for 16 samples
    //--------------------------------      
    AD1CSSL = 0x03;                  // Channel AN0 and Channel AN1
    AD1CON1bits.SSRC = 0x07;         // Trigger
    AD1CON3bits.SAMC = 0x0F;         // 16 tads for sampling
    AD1CON2bits.SMPI = defAdcSampleCount-1;  // After 2 samples
    AD1CON2bits.CSCNA = 1;
    AD1CON1bits.MODE12 = 1;          // 12-bit
    AD1CON1bits.FORM = 0x00;         // Absolute result
    AD1CON1bits.ADON = 1;            // Enable Adc

    // Timer1
    //--------------------------------
    T1CON = 0x0200;
    PR1 = 32;
    IEC0 = 0x2008;                   // Enable Timer Interrupt T1IE
    T1CONbits.TCS = 1;
    T1CONbits.TECS = 2;
    T1CONbits.TON = 1;
    INTCON2 = 0x8000;                // Enable Global Interrupts
}

/*******************************
 *      Main
 *******************************/
int main(void) {
    int32_t i32Temperature;
    int32_t i32DifferenceX;
    int32_t i32DifferenceY;
    uint8_t ui8Index;
    uint8_t ui8SelectSegment = 0;
    uint8_t ui8SegmentShiftDirection = 0;
    uint8_t ui8CharacterOffset = 0;

    // Initialization
    vInitHardware();
    while(1){
        
        // Scheduler: Set Scheduler Bits
        //-----------------------------------------
        if( xScheduleStatus.ui8Interrupt1ms){
            xScheduleStatus.ui8Interrupt1ms = 0;
            
            ++xScheduleStatus.ui8Counter3ms;
            ++xScheduleStatus.ui8Counter7ms;
            ++xScheduleStatus.ui8Counter10ms;
            
            if(xScheduleStatus.ui8Counter3ms == 3){
                xScheduleStatus.ui8Counter3ms = 0;
                xScheduleStatus.ui16TimerSchedule3ms = 1;
            }
            
            if(xScheduleStatus.ui8Counter7ms == 7){
                xScheduleStatus.ui8Counter7ms = 0;
                xScheduleStatus.ui16TimerSchedule7ms = 1;
            }
            
            if(xScheduleStatus.ui8Counter10ms == 10){
                xScheduleStatus.ui8Counter10ms = 0;
                xScheduleStatus.ui16TimerSchedule10ms = 1;
                ++xScheduleStatus.ui8Counter10msBase;
                
                 if(xScheduleStatus.ui8Counter10msBase%50 == 0){
                    xScheduleStatus.ui16TimerSchedule500ms = 1;
                }
                
                if(xScheduleStatus.ui8Counter10msBase%10 == 0){
                    xScheduleStatus.ui16TimerSchedule100ms = 1;
                }
                if(xScheduleStatus.ui8Counter10msBase%5 == 0){
                    xScheduleStatus.ui16TimerSchedule50ms = 1;
                }

                if(xScheduleStatus.ui8Counter10msBase == 100){
                     xScheduleStatus.ui8Counter10msBase = 0;
                    xScheduleStatus.ui16TimerSchedule1000ms = 1;
                }
            }
            xScheduleStatus.ui16TimerSchedule1ms = 1;
        }
        
        // Scheduled Tasks
        //-------------------------------------------------------
        // 7-Segment: Character rolling
        if(xScheduleStatus.ui16TimerSchedule500ms){
            if(ui8SegmentShiftDirection){
                ui8CharacterOffset = (ui8CharacterOffset-1);
                if(ui8CharacterOffset == 0){
                    ui8SegmentShiftDirection =~ui8SegmentShiftDirection;
                }
            }else{
                ui8CharacterOffset = (ui8CharacterOffset+1);
                if(ui8CharacterOffset == (sizeof(defString)-1-3)){
                    ui8SegmentShiftDirection =~ui8SegmentShiftDirection;
                }
            }
            
        }
        if(xScheduleStatus.ui16TimerSchedule100ms){
             //ui16SpiCommunicateWithPoti((0x00<<defSpiAddressShift)|defSpiCommandWriteMask|defSpiCommandCmdErrorMask,1);
             ui16SpiCommunicatePoti((0x04<<defSpiAddressShift)|defSpiCommandReadMask, 0xFF);

            //ui16SpiCommunicateWithPoti((0x05<<defSpiAddressShift)|defSpiCommandReadMask|defSpiCommandCmdErrorMask,1);
        }
        
        // 7-Segment: Time multiplex
        if(xScheduleStatus.ui16TimerSchedule1ms){
            //vSetSegmentCharacter(arrchString[ui8SelectSegment+ui8CharacterOffset],ui8SelectSegment);
            ui8SelectSegment =(ui8SelectSegment+1)%3;
        }
        
        // Fetch Adc: Synchronized on new data
        if(xAdcStatus.ui16AdcNewDataAvailable){
            xAdcStatus.ui16AdcNewDataAvailable = 0;
            
            xAdcStatus.ui16AdcChannelNtc = 0;
            xAdcStatus.ui16AdcChannelReference = 0;
            for(ui8Index=0;ui8Index<defAdcSampleCount;ui8Index+=2){
                xAdcStatus.ui16AdcChannelNtc += (*((&ADC1BUF0)+ui8Index));
                xAdcStatus.ui16AdcChannelReference += (*((&ADC1BUF1)+ui8Index));
            }

            xAdcStatus.ui16AdcChannelNtc >>= defAdcSampleShift;    
            xAdcStatus.ui16AdcChannelReference >>=defAdcSampleShift;    
            xAdcStatus.i16AdcChannelDifference = xAdcStatus.ui16AdcChannelReference-xAdcStatus.ui16AdcChannelNtc;
            
            // Ntc
            // Circuit: 1k  = 3.3k*(1k/(1k+1k)) = 1.65V -> 0x7FF   
            // Precision: 3%  +- 61 dec
            // Linearisierung: Werte -55 bis 70
            for(ui8Index=0; ui8Index<26;++ui8Index){
                    
                // When region found interpolate between two values
                if(xAdcStatus.i16AdcChannelDifference<arri16QTemperatureValues[ui8Index]){
                    
                    // Interpolation: y = y0 + (x-x0)*(y1-y0)/(x1-x0)
                    i32DifferenceX = (int32_t)(arri16QTemperatureValues[ui8Index]-arri16QTemperatureValues[ui8Index-1]);
                    i32DifferenceY = ((int32_t)(defQStart + ui8Index*defQStep)<<10)  -  ((int32_t)(defQStart + (ui8Index-1)*defQStep)<<10);               // Multiply by 1024
                    i32Temperature = (i32DifferenceY*(xAdcStatus.i16AdcChannelDifference-arri16QTemperatureValues[ui8Index-1]));
                    i32Temperature /= i32DifferenceX;
                    i32Temperature +=((int32_t)(defQStart + (ui8Index-1)*defQStep)<<10);        
                    i32Temperature >>=6;        // Lower 4 bits symbolize fixed point
                    
                    //vFormatTemperatureIntoBuffer(arrchString, 0, i32Temperature);   
                    break;
                }
            }

            //vFormatIntIntoBuffer(arrchString,0,xAdcStatus.ui16AdcChannelNtc);
            //vFormatIntIntoBuffer(arrchString,5,xAdcStatus.ui16AdcChannelReference);
        }
        
        xScheduleStatus.ui16TimerSchedule = 0x0000;                 // Reset Scheduler flags
    }
    return 0;
}

/****************************
 *      Timer 1 Interrupt
 ****************************/
void  __attribute__((__interrupt__, no_auto_psv)) _T1Interrupt(void){
    if(IFS0bits.T1IF){
      IFS0bits.T1IF = 0;                // Clear timer interrupt flag
      AD1CON1bits.ASAM = 1;             // Conversion is started on timer interrupt. Conversion is synced with timer.
      ++xScheduleStatus.ui8Interrupt1ms;    
    }
}

/****************************
 *      ADC Interrupt
 ****************************/
void  __attribute__((__interrupt__, no_auto_psv)) _ADC1Interrupt(void){
    if(IFS0bits.AD1IF){
        AD1CON1bits.ASAM = 0;                   // Stop Conversion
        IFS0bits.AD1IF = 0;
        xAdcStatus.ui16AdcNewDataAvailable = 1;
    }
}

/****************************
 *      Oscillator Fail Trap
 ****************************/
void __attribute__((interrupt,no_auto_psv)) _OscillatorFail(void){
    INTCON1bits.OSCFAIL = 0;
    ui8TrapErrorStatus = 1;
}

/****************************
 *      Address Error Trap
 ****************************/
void __attribute__((interrupt,no_auto_psv)) _AddressError(void){
    INTCON1bits.ADDRERR = 0;
    ui8TrapErrorStatus = 2;
}

/****************************
 *      Stack Error Trap
 ****************************/
void __attribute__((interrupt,no_auto_psv)) _StackError(void){
    INTCON1bits.STKERR = 0;
    ui8TrapErrorStatus = 3;
}

/****************************
 *      Math Error Trap
 ****************************/
void __attribute__((interrupt,no_auto_psv)) _MathError(void){
    INTCON1bits.MATHERR = 0;
    ui8TrapErrorStatus = 4;
}

/****************************
 *      NVM Error Trap
 ****************************/
void __attribute__((interrupt,no_auto_psv)) _NVMError(void){
    ui8TrapErrorStatus = 5;
    
}

/****************************
 *      General Error Trap
 ****************************/
void __attribute__((interrupt,no_auto_psv)) _GeneralError(void){
    ui8TrapErrorStatus = 6;
}

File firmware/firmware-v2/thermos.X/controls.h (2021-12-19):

/* Microchip Technology Inc. and its subsidiaries.  You may use this software 
 * and any derivatives exclusively with Microchip products. 
 * 
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
 * IN NO EVENT WILL MICROCHIP BE LIABLE FOR ANY INDIRECT, SPECIAL, PUNITIVE, 
 * INCIDENTAL OR CONSEQUENTIAL LOSS, DAMAGE, COST OR EXPENSE OF ANY KIND 
 * WHATSOEVER RELATED TO THE SOFTWARE, HOWEVER CAUSED, EVEN IF MICROCHIP HAS 
 * BEEN ADVISED OF THE POSSIBILITY OR THE DAMAGES ARE FORESEEABLE.  TO THE 
 * FULLEST EXTENT ALLOWED BY LAW, MICROCHIP'S TOTAL LIABILITY ON ALL CLAIMS 
 * IN ANY WAY RELATED TO THIS SOFTWARE WILL NOT EXCEED THE AMOUNT OF FEES, IF 
 * ANY, THAT YOU HAVE PAID DIRECTLY TO MICROCHIP FOR THIS SOFTWARE.
 *
 * MICROCHIP PROVIDES THIS SOFTWARE CONDITIONALLY UPON YOUR ACCEPTANCE OF THESE 
 * TERMS. 
 */

/* 
 * File:   
 * Author: 
 * Comments:
 * Revision history: 
 */

#ifndef CONTROLS_H
#define	CONTROLS_H


/*****************************
 * 
 * Defines
 * 
 *****************************/

// Multiple of 2's
#define defAdcSampleCount (8*2)
#define defAdcSampleShift 3

#define defResetSegmentBars(){ LATE |= 0x000F; LATF |= 0x0002; LATG|=0x0180; LATC |=0x8000;}
#define defSetBarA() LATC = (LATC)& ~0x8000;   
#define defSetBarB() LATF = (LATF)& ~0x0002;   
#define defSetBarC() LATE = (LATE)& ~0x0008;   
#define defSetBarD() LATG = (LATG)& ~0x0080;  
#define defSetBarE() LATG = (LATG)& ~0x0100;
#define defSetBarF() LATE = (LATE)& ~0x0002;
#define defSetBarG() LATE = (LATE)& ~0x0001;  
#define defSetBarDP() LATE = (LATE)& ~0x0004;


#define defDisableSegments() LATB = (LATB|0xC400);
#define defEnableSegment(x) if(x == 0)LATB =(PORTB&0x7FFF); else if(x==1)LATB =(PORTB&0xBFFF); else LATB =(PORTB&0xFBFF);

#define defQStart  -55
#define defQStep     5
#define defString "   8888   "

#define defSpiCsPoti(x) if(x) LATC |= (0x1000); else LATC &= (~0x1000); 
#define defSpiCsWaitCycles            10
#define defSpiAddressShift             4
#define defSpiCommandShift             2
#define defSpiCommandCmdErrorMask   (0x03<<0)
#define defSpiCommandReadMask       (0x03<<defSpiCommandShift)|defSpiCommandCmdErrorMask
#define defSpiCommandWriteMask      (0x00<<defSpiCommandShift)|defSpiCommandCmdErrorMask
#define defSpiCommandIncrementMask  (0x01<<defSpiCommandShift)|defSpiCommandCmdErrorMask
#define defSpiCommandDescrementMask (0x02<<defSpiCommandShift)|defSpiCommandCmdErrorMask


#endif	

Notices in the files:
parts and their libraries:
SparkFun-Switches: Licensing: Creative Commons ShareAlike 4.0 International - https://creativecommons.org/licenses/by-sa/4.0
